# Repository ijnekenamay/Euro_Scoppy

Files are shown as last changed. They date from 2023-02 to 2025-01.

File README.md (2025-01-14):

# Euro_Scoppy
Project to make an Eurorack version of "([Scoppy](https://play.google.com/store/apps/details?id=xyz.fhdm.scoppy&hl=ja&gl=US))" oscilloscope that works with Raspberry pi pico and Android phone.

!!!!!!! note !!!!!!!!
- I had long forgotten about this project. I finished the test build and verified that it works fine, but then I remembered I needed another oscilloscope for calibration and threw it away. Nothing wrong with just looking at the waveform shape. Enjoy.
- Be sure to use a cable with “OTG” function. This is also shown in the Scoppy reference.
- Payment for the "Scoppy" application is required to use the two channels.
- This project is ongoing.

## Now progress

- [x] Idea sketch
- [x] Draw proto Schematics
- [x] Design proto PCB
- [x] Proto type
- [x] Design PCB
- [x] Fabrication PCB
- [x] Test Build

## Latest Status

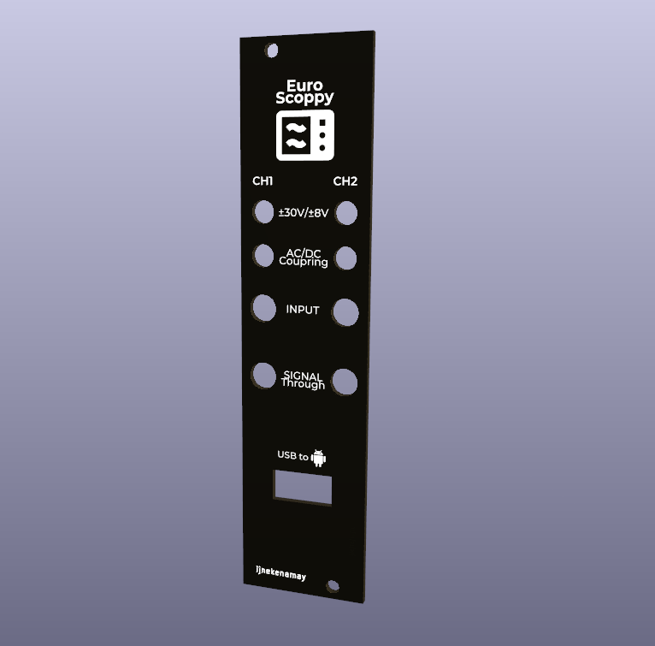
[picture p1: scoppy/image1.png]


## Feature

- Two channels of input are available.
- AC/DC coupling can be selected for each input.
- ±30V and ±8V can be changed.
- It is based on an analog front-end PCB designed by [picoLABO](https://picolabo.org/plu2212-dso/)).

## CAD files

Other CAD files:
LIB_TZ03R300F169B00/TZ03R300F169B00/Allegro/tz03_b_.psm
LIB_TZ03R300F169B00/TZ03R300F169B00/DEHDL/tz03r300f169b00/chips/chips.prt

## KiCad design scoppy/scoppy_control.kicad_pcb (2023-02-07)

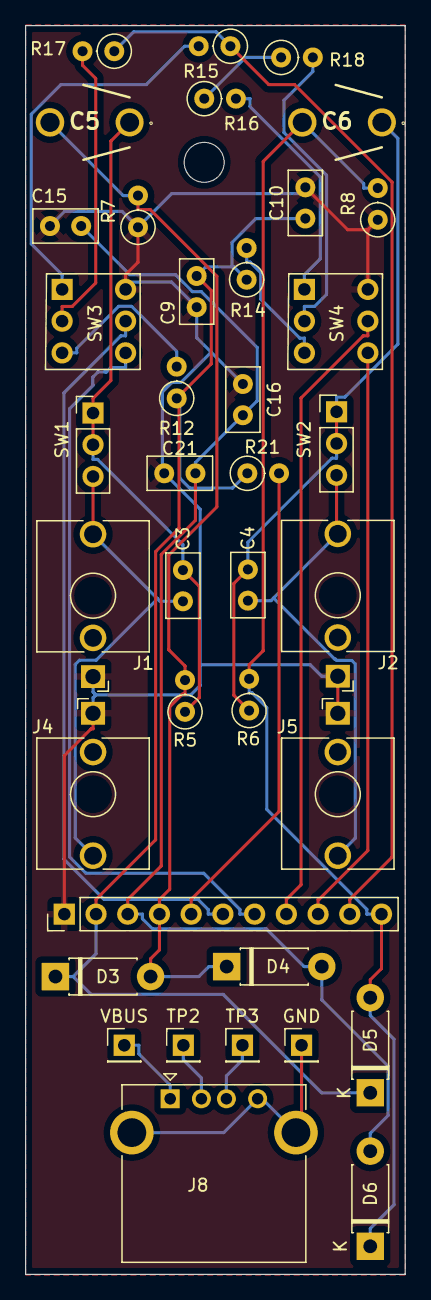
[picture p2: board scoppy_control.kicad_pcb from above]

Board: 2 copper layers, 30.4 x 100.0 mm, 39 parts (0 on the bottom side), 26 nets.

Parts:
C3, C4, C9, C10, C15, C16: 0.1uF; C_Disc_D5.0mm_W2.5mm_P2.50mm
C5, C6: 30pF; TZ03_B_
C21: 10uF; C_Disc_D5.0mm_W2.5mm_P2.50mm
D3, D4, D5, D6: D_Schottky; D_DO-41_SOD81_P7.62mm_Horizontal
GND: GND; PinHeader_1x01_P2.54mm_Vertical
J1: CH1; Jack_3.5mm_QingPu_WQP-PJ398SM_Vertical_CircularHoles
J2: CH2; Jack_3.5mm_QingPu_WQP-PJ398SM_Vertical_CircularHoles
J4: CH1_Through; Jack_3.5mm_QingPu_WQP-PJ398SM_Vertical_CircularHoles
J5: CH2_Through; Jack_3.5mm_QingPu_WQP-PJ398SM_Vertical_CircularHoles
J8: USB_A; USB_A_CONNFLY_DS1095-WNR0
R5, R6: 1M; R_Axial_DIN0207_L6.3mm_D2.5mm_P2.54mm_Vertical
R7, R8: 100k; R_Axial_DIN0207_L6.3mm_D2.5mm_P2.54mm_Vertical
R12, R14, R21: 15k; R_Axial_DIN0207_L6.3mm_D2.5mm_P2.54mm_Vertical
R15, R16: 180R; R_Axial_DIN0207_L6.3mm_D2.5mm_P2.54mm_Vertical
R17, R18: 1k; R_Axial_DIN0207_L6.3mm_D2.5mm_P2.54mm_Vertical
REF1: MountingHole_3.2mm_M3
REF5: PinHeader_1x11_P2.54mm_Vertical
SW1, SW2: AC/DCcoupling; PinHeader_1x03_P2.54mm_Vertical
SW3, SW4: Switch±30V/±8V/; toggle_dpdt_mod
TP2: TP2; PinHeader_1x01_P2.54mm_Vertical
TP3: TP3; PinHeader_1x01_P2.54mm_Vertical
VBUS: VBUS; PinHeader_1x01_P2.54mm_Vertical

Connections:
+3V3: C9.2, C10.2, D3.1 (K), D5.1 (K), R12.1, R14.1, R21.1, REF5.2
-3V3: C15.2, C16.2, C21.1, D4.2 (A), D6.2 (A), REF5.3
CH1: C3.1, J1.T, J4.T, SW1.3 (C)
CH2: C4.1, J2.T, J5.T, SW2.3 (C)
GND: C9.1, C10.1, C15.1, C16.1, C21.2, J1.S, J2.S, J4.S, J5.S, R7.1, R8.1, REF5.1, SW3.2 (B), SW4.2 (B)
GPIO2: REF5.6, SW3.4 (A)
GPIO3: REF5.7, SW3.6 (C)
GPIO4: REF5.8, SW4.4 (A)
GPIO5: REF5.9, SW4.6 (C)
unnamed: C3.2, C5.1, R5.1, SW1.1 (A), SW1.2 (B)
unnamed: C4.2, C6.1, R6.1, SW2.1 (A), SW2.2 (B)
unnamed: C5.2, D3.2 (A), D4.1 (K), R5.2, R7.2, REF5.4
unnamed: C6.2, D5.2 (A), D6.1 (K), R6.2, R8.2, REF5.11
unnamed: R21.2, REF5.5
unnamed: GND.1, J8.4 (GND), J8.5 (Shield)
unnamed: J8.1 (VBUS), VBUS.1
unnamed: J8.3 (D+), TP3.1
unnamed: J8.2 (D-), TP2.1
unnamed: R15.1, R17.1, REF5.10
unnamed: R12.2, SW3.5 (B)
unnamed: R16.1, R18.1
unnamed: R14.2, SW4.5 (B)
unnamed: R15.2, SW3.1 (A)
unnamed: R16.2, SW4.1 (A)
unnamed: R17.2, SW3.3 (C)
unnamed: R18.2, SW4.3 (C)

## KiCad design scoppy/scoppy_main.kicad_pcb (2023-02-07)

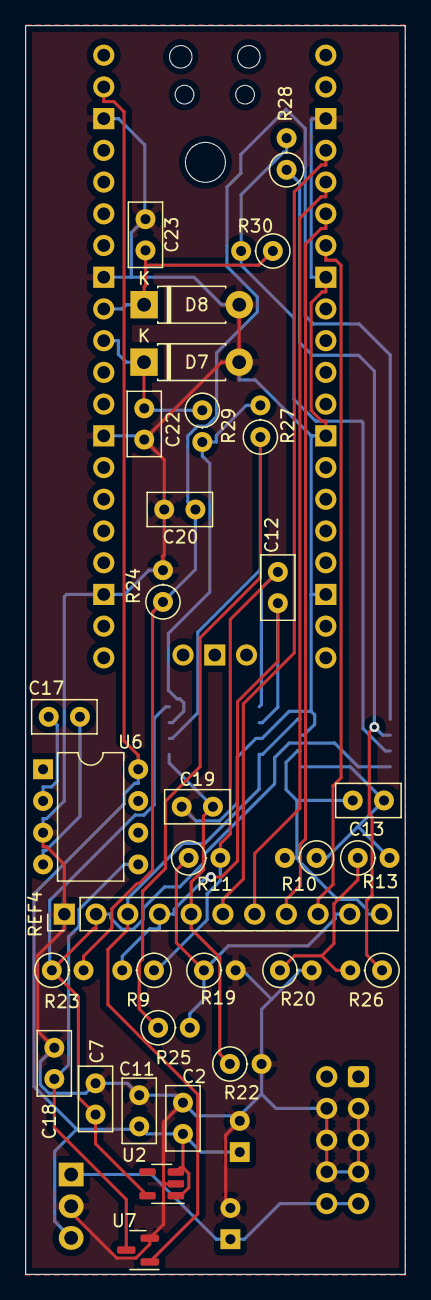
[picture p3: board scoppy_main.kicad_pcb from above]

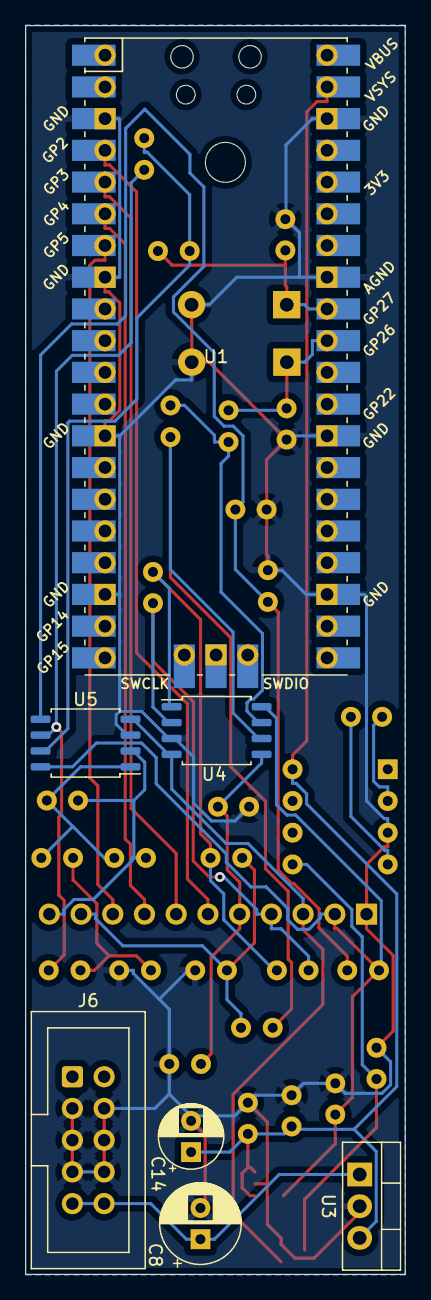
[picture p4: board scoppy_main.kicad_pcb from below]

Board: 2 copper layers, 30.4 x 100.0 mm, 40 parts (7 on the bottom side), 26 nets.

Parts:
C2, C7, C11, C17, C18: 10uF; C_Disc_D5.0mm_W2.5mm_P2.50mm
C8: 100uF; CP_Radial_D6.3mm_P2.50mm
C12, C13, C22, C23: 200p; C_Disc_D5.0mm_W2.5mm_P2.50mm
C14: 10uF; CP_Radial_D5.0mm_P2.50mm
C19, C20: 0.1uF; C_Disc_D5.0mm_W2.5mm_P2.50mm
D7, D8: D_Schottky; D_DO-41_SOD81_P7.62mm_Horizontal
J6: POWER; IDC-Header_2x05_P2.54mm_Vertical
R9, R10: 100k; R_Axial_DIN0207_L6.3mm_D2.5mm_P2.54mm_Vertical
R11, R13, R29, R30: 2.7k; R_Axial_DIN0207_L6.3mm_D2.5mm_P2.54mm_Vertical
R19, R20, R27, R28: 220k; R_Axial_DIN0207_L6.3mm_D2.5mm_P2.54mm_Vertical
R22, R24: 1k; R_Axial_DIN0207_L6.3mm_D2.5mm_P2.54mm_Vertical
R23: 15k; R_Axial_DIN0207_L6.3mm_D2.5mm_P2.54mm_Vertical
R25, R26: 30k; R_Axial_DIN0207_L6.3mm_D2.5mm_P2.54mm_Vertical
REF2: MountingHole_3.2mm_M3
REF4: PinHeader_1x11_P2.54mm_Vertical
U1: Pico; RPi_Pico_SMD_TH
U2: XC6201; SOT-23-5
U3: LM7805_TO220; TO-220-3_Vertical
U4, U5: NJM2746M; SOP-8_5.28x5.23mm_P1.27mm
U6: ICL7660; DIP-8_W7.62mm
U7: XC6902; SOT-23

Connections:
+3V3: C7.1, R23.1, REF4.2, U2.5 (VOUT), U4.8 (V+), U5.8 (V+)
+5V: C2.1, C11.1, C14.1, U1.39 (VSYS), U2.1 (VIN), U2.3 (CE), U3.3 (VO), U6.8 (V+)
+12V: C8.1, J6.9, J6.10, U3.1 (VI)
-3V3: REF4.3, U4.4 (V-), U5.4 (V-), U7.1 (VO)
-5V: C18.1, U6.5 (VOUT), U7.3 (VI)
ADC0: C22.2, D7.1 (K), R29.1, U1.31 (GPIO26_ADC0)
ADC1: C23.2, D8.1 (K), R30.1, U1.32 (GPIO27_ADC1)
GND: C2.2, C7.2, C8.2, C11.2, C14.2, C18.2, C19.1, C20.1, C22.1, C23.1, D7.2 (A), D8.2 (A), J6.3, J6.4, J6.5, J6.6, J6.7, J6.8, R19.2, R20.2, R22.2, R24.2, REF4.1, U1.3 (GND), U1.8 (GND), U1.13 (GND), U1.18 (GND), U1.23 (GND), U1.28 (GND), U1.33 (AGND), U1.38 (GND), U2.2 (GND), U3.2 (GND), U4.3 (+), U5.3 (+), U6.3 (GND), U7.2 (GND)
GPIO2: REF4.6, U1.4 (GPIO2)
GPIO3: REF4.7, U1.5 (GPIO3)
GPIO4: REF4.8, U1.6 (GPIO4)
GPIO5: REF4.9, U1.7 (GPIO5)
unnamed: C12.1, R9.2, REF4.4, U4.2 (-)
unnamed: C12.2, R9.1, R11.2, U4.1
unnamed: C13.1, R10.2, REF4.11, U5.2 (-)
unnamed: C13.2, R10.1, R13.2, U5.1
unnamed: C17.1, U6.2 (CAP+)
unnamed: C17.2, U6.4 (CAP-)
unnamed: C19.2, R22.1, REF4.5, U4.5 (+)
unnamed: C20.2, R23.2, R24.1, U5.5 (+)
unnamed: R11.1, R19.1, R25.2, REF4.10
unnamed: R13.1, R20.1, R26.2
unnamed: R25.1, R27.1, U4.6 (-)
unnamed: R26.1, R28.1, U5.6 (-)
unnamed: R27.2, R29.2, U4.7
unnamed: R28.2, R30.2, U5.7
